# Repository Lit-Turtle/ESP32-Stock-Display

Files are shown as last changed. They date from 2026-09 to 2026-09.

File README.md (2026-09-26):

# ESP32-Stock-Display

https://github.com/user-attachments/assets/17d52d09-3d5c-4d5f-b84c-951d37e83fe0

This project displays live stock prices on a mirror-like display, with display specifics easily changeable through a local network(access point). The ESP32 acts as a STA mode enabling this to be a true IOT device. A robust power system allows this device to run on the recommended 9V from a USB-C input; switch on side to easily enable or disable the device; and a photoresistor to automatically turn off the device when the environment is dark. 

## Features

- 32 by 8 dot matrix display to easily display stock prices and animations.
- Mirror-like display that hides the grid pattern from dot matrix only allowing the powered lights to shine through.
- Wall anchors to easily setup display using screws or any wall hooks. 
- USB-C power plug, used for its widespread usage and that many people already have one.
- Robust power system, with side switch to quickly disable the display. Adjustable circuit that reactively cuts power if the surrounding environment is dark, for when sleeping or room lights or turned off. 
- Local network set up through the ESP32 allows any internet device connected to the same network to change what the display shows. 
- IOT device capabilities through the ESP32 connected to your wifi network, which grabs the live stock prices and the fear & greed index. 

## Tech Stack

**Hardware:** ESP32, MAX7219 32×8 LED Matrix, LM393 Comparator, NMOSFET, Photoresistor, USB-C PD Module  
**Software:** C++, Arduino IDE, HTML/CSS, JavaScript  
**CAD/PCB:** SolidWorks, KiCad  
**Manufacturing:** JLCPCB, 3D Printing  
**Connectivity:** Wi-Fi, REST APIs, Local Web Server

## Goal

The goal of this project is to develop a functional IoT device that can be easily integrated into users’ life. More specifically, creating an affordable stock ticker that can be easily customized to match individual financial strategies. 

## Why?

Being introduced to investing from a young age, I decided one day I want to see how much a stock ticker would be if I got one. So like most I searched it up on Amazon to see that prices ranged from $50 to $100 plus. When I got my hands on an ESP32 for the first time, I realized that a stock ticker would be something I can build. 

## System Architecture

Stock Ticker System Arch

## Design Process

### Initial Design

The general idea for the stock ticker has remained the same throughout, which is to use the ESP32 as the microcontroller in order to get data and the dot matrix for the display. I did consider a LCD screen, however I went with a dot matrix as I already had it on hand and it would be easier to see from afar.

The casing was not as set in stone, however I had some key features that I wanted to implement. Which is a compact case with straightforward wiring, easy to access ESP32, and secure dot matrix holder with screen holder in front. 

The PCB that disables and enables power depending on surrounding light level, was not initially part of the plan. However, the idea came in during the early design process while an improved light system was an improvement already being considered.

### Hardware Selection

ESP32 microcontroller for its wifi and web server capabilities. A perfect beginner microchip for IoT projects and ability to be programmed with C++ on Arduino IDE.  

MAX7219 dot matrix chosen for its financial aesthetic. Ability to display still and scrolling text without the need for fonts, with relatively simple ways to draw art.

JLCPCB for PCB fabrication as they have been reliable and affordable throughout the time I have used their service. For this project I also utilized their parts assembly service to have them solder the resistors, LM393, potentiometer, and mosfet. A PCB was used for the power system as it requires a decent amount of components, so PCB saves space and decreases opportunity for error.    

### PCB Development

The PCB board also had a couple iterations. Some were due to errors that either made the board faulty or gave unintended results. Other than errors some key changes were the use of a potentiometer with now facing upwards instead to the side for easier access when placed in a narrow case. Another change was the location of the 2 wires in and 2 wires out which were moved for easier assembly when in case, as power input is located on one side while the load is located on the opposite end. 

An annoying roadblock I ran into was regarding KiCad and its mosfets. Most mosfets use pinout gate, drain, source, however kiCad actually does not have a default footprint for that so you have to edit the pin number accordingly. Or else once you go into the PCB editor it will say you have it traced correctly but once you solder your mosfet it won’t work because the pins are different. For my situation the mosfet was drain, gate, source but my real life mosfet was gate, drain, source. So I had to flip the pin number for drain pin and gate pin in the schematic editor, when you click on component and edit footprint. 

### Enclosure Development

The case had 3 iterations, however each iteration had only minor iterations. The 1st to 2nd: adjusting wall mounting hole placement, lowered esp32 area to give space to wires from bottom of ESP32, addition of wire passing area from ESP32 to dot matrix, resizing of USB-C hole, and holding side walls for PD module. 2nd to final iteration is just the addition PCB holding ramps in the power section.

The PD module holding cap piece had quite a few iterations due to the fittings/holding method making it too snug or too loose. With such small dimensions and scenarios where proper fit was needed it of course can with some iterations. Other than small dimension changes the main change was a roof over the screw terminals which greatly benefitted the fit. 

### Screen Development

The screen is a glass piece. For my display I ordered a plexiglass due to it being cheaper. Though, any see-through material with the matching dimensions can be used. 

Mirror Screen

In order to hide the grid pattern from the dot matrix, I tested a couple different options. First, was frosted glass film, however, this blurred the light or had no effect due to the fact that the matrix was right next to the glass. A tint is also an optional film, however I found that it often blurs the light a bit too much, making text a bit difficult to read.

The recommended option is to use some sort of tint, the darkness varies to preference. However, for my project I decided to use a one way mirror tint as it completely hides the grid. Additionally, when turned off it looked like a regular mirror but when enabled gave a cool light in mirror effect. The exact ordered materials can be found below in the parts list. 
The screen was an area that proved to be sort of difficult. If the piece fits the dimensions 147mm x 41mm x 4mm it will be a great fit for the case. For my project I ordered plexiglass and a couple different filters. I will later mention what I tried but what worked was the tinted mirror filter. However, if your budget is greater, I would recommend getting glass instead of plexiglass. The plexiglass, at least that I ordered, has some uneven/bumpy surface which makes the tint difficult to apply, but even once applied some bumps are still noticeable. It does not make the text illegible however for a better look, a glass piece would be recommended. 

## Light ON/OFF PCB Board

The circuit was first designed on a breadboard to test the circuit design and concept.

LightOnOFFBreadboard

LightOnOffSchematic

This circuit’s main component is the LM393 Comparator which compares the voltage between 2 input voltages. The 2 input voltages for our case will be determined by the photoresistor and potentiometer voltage dissipated. This means if potentiometer resistance is greater than photoresistor’s resistance then power is supplied and not supplied if reverse. Note that the photoresistor has increased resistance when dark. 

The 10k ohm resistor R3 acts as a pull-down resistor creating a potential difference to actually flow through the photoresistor so that there is voltage to be compared for the LM393, there must be a resistor in order to have the potential difference across be the full 9V through a voltage divider. The 10k ohm resistor R4 acts as a pull-up resistor because the LM393 is open-collector output. This is necessary for whenever the output is HIGH as it helps open the transistor gate. While the 1k ohm resistor R2 is necessary as the NMOSFET gate can cause current spikes and this resistor protects the comparator from these spikes. 

LightOnOffPCBEditor

Some key pieces to note are as follows. The vertical potentiometer though taking more space was selected for easier adjusting of potentiometer value due to the narrow width of the power area. Also the LM393 comparator has 2 comparators built in but only one was used. For my case I used pins 1, 2, and 3. It is key not to forget to connect pin 4 for ground and pin 8 for power in order to power the comparator. Another additional piece is the logo engraved in the top right, which was added for a more professional look and for copyright protection.

SolderedPCB

The PCB board was designed using kiCad and manufactured by JLCPCB. Some components were also soldered by JLCPCB.

## Enclosure

The shell of our display has 3 main pieces and one additional piece. Each part was designed in SolidWorks. 

CaseBaseShaded

The first and most important piece is the base piece, which is the largest piece which holds all the components. The base piece has 3 main sections. The first is our power area which is where our switch, power input, and our pcb board will be located. The one connected to that is where our ESP32 will be located. The big area is then where our dot matrix display will be located and as you can see we have the small area to the right of that which is where the wiring between the ESP32 and dot matrix will pass through. 

CaseCHolder

Some key features of the base is a cut out and shaping of our USB-C plug, which was designed to securely hold the PD lonely binary module.

CaseIndent

CaseWallMountShaded

Another important area is the indent which will be important when it comes to our third piece. Lastly our wall mount which was designed for screws drilled into the wall or any similar mounting piece. This is an optional piece only for those who want to mount the display on a wall. However, this neat design allows for easy hooking of display if you choose to do so.  



The second piece is the roof of our case. This piece encloses the entire display. Attached to the base via the 4 aligning holes that were seen on the base. Which can then be connected using screws of your choice. There is one non-circular hole which is where you should pass the photoresistor through.

DisplayScreen

The last piece is a purchased piece and is the glass used to not only hold the matrix upright but also as a protector/screen for our display. This piece is also where chosen filters or tints can be applied onto. The main thing is the dimensions of the class, which is recommended to be 147mm x 41mm x 4mm. 

## Electrical/Wiring

The wiring of the display is relatively simple. Going by each section of the base it will be as follows.

For the power area, the power will first start from our PD USB-C module. This module was selected for its capabilities to easily switch between different voltage supplies. 

PD Module

This module will have 2 wires for power and ground. The positive end will then connect in series with the switch, which will connect to the PCB board along with our ground. Exiting the PCB board will be the load voltage out and load voltage back. These 2 wires will be the only 2 leaving from the power area.

These 2 wires will simply connect to the Vin and GND of the ESP32 located in the adjacent section.

Between the dot matrix and ESP32 will be 5 separate wires: VCC, GND, DIN, CS, and CLK. These should connect to the corresponding pins in the code, which will be discussed next.

## ESP32 Code

The ESP32 was programmed through the Arduino IDE. The entire details of the code will not be explained here as the code already contains comments.

Libaries from Arduino IDE used in this program are:
- ArduinoJson by Benoit Blanchon
- MD_MAX72XX by majicDesigns
- MD_Parola by majicDesigns

The ESP32 is established as STA and AP mode, which means you will need to enter your own wifi network information for the ESP32 to function properly. You will also need to import some libraries for you to set up local sites and display everything text/images on the matrix. 

The key idea is that through the site users can select different modes that change what the display shows. If we are displaying stock prices or fear & greed indexes, the ESP32 will grab these prices or index through an api key and display the data.

You may easily add or modify existing modes to display what you would like. To add mode you would need to modify the 
```
enum DisplayMode { MODE_VOO, MODE_FEAR_GREED… };
```
Just add or remove any modes you would like. Then add or remove that option from our switch case.
```
switch(currentMode) {
	case MODE_VOO:
		html += “VOO Price”;
		break;
	case MODE_FEAR_GREED:
		html += “FEAR GREED INDEX”;
		break;
	…
}
```
A few lines down add options as well.
```
html += “<option value=’voo’” + String(currentMode == MODE_VOO ? “ selected” : “”) + “>VOO Price</option>”;
```

You will also need to add your new mode on line 265. 
```
If (mode == “voo”) 
	currentMode = MODE_VOO;
```
Lastly, in refreshData() you will also want to add another case for your new mode. 
```
void refreshData() {
 	String text;
  	switch (currentMode) {
    		case MODE_VOO:        
      		text = "" + getVOO();  
      		break;
```

If you are going to be grabbing data you may want to create a new get_() method. 

I will not bore you with the entire explanation but the code, with comments, will be included in this repository. 

## Final Assembly

https://youtu.be/V5j7vDCx7zQ

For a step-by-step guide to assembling the enclosure and electronics, see the [Assembly Guide](ASSEMBLY.md).

## Future Improvements

Some future improvements I would like to make is having a multi-color matrix display, so that way the color can indicate whether price is up or down and fear or greed. 

Another area is with the code, through the STA and AP mode with the matrix display, the display can really display any data you would like, just by modifying the code. Some examples are sport scores, Spotify listening/lyrics, weather, and any information you can grab data for.

## Parts List

[Filament](https://store.creality.com/products/hyper-pla-rfid-3d-printing-filament-1kg)

[Plexiglass](https://www.aliexpress.us/item/3256803346944118.html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)
Specific dimensions may need to be requested.

[Regular Tint](https://www.aliexpress.us/item/3256806769429614.html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) 

[Mirror Tint](https://www.aliexpress.us/item/3256805054544955.html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)

[PD Module](https://www.amazon.com/dp/B0GTTTGJNX?ref=ppx_yo2ov_dt_b_fed_asin_title)

[ESP32 Dev Kit](https://www.amazon.com/AITRIP-ESP-WROOM-32-Development-Microcontroller-Integrated/dp/B0CR5Y2JVD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)

[Dot Matrix](https://www.aliexpress.us/item/3256805668841965.html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)

[Switch](https://www.aliexpress.us/item/3256809828963002.html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)

[Photoresistor](https://www.amazon.com/dp/B0CM5YNGSF?ref=ppx_yo2ov_dt_b_fed_asin_title&th=1)

[Heat Press Thread Insert](https://www.amazon.com/dp/B0CTCH68LT?ref=ppx_yo2ov_dt_b_fed_asin_title)

[M3 8mm Screws](https://www.amazon.com/dp/B07CMSBQ11?ref=ppx_yo2ov_dt_b_fed_asin_title&th=1)

---

Part Number for Components

Potentiometer: LCSC Part # C116302

LM393 Comparator: LCSC Part # C5252905

NMOSFET: LCSC Part # C2557

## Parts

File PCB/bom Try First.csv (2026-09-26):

Designator | Footprint | Quantity | Value | LCSC Part #
Q1 | TO-220F-3_Vertical | 1 | NMOS | C2557
R1 | R_LDR_D6.4mm_P3.4mm_Vertical | 1 | R_Photo
R2 | 805 | 1 | 1kR | C17513
R3, R4 | 805 | 2 | 10kR | C17414
RV1 | Potentiometer_Bourns_3386P_Vertical | 1 | R_Pot | C116302
U1 | DIP-8_W7.62mm | 1 | LM393P | C5209
U2 | 9V Input | 1 | ~
U3 | 9VLoadFoot | 1 | ~

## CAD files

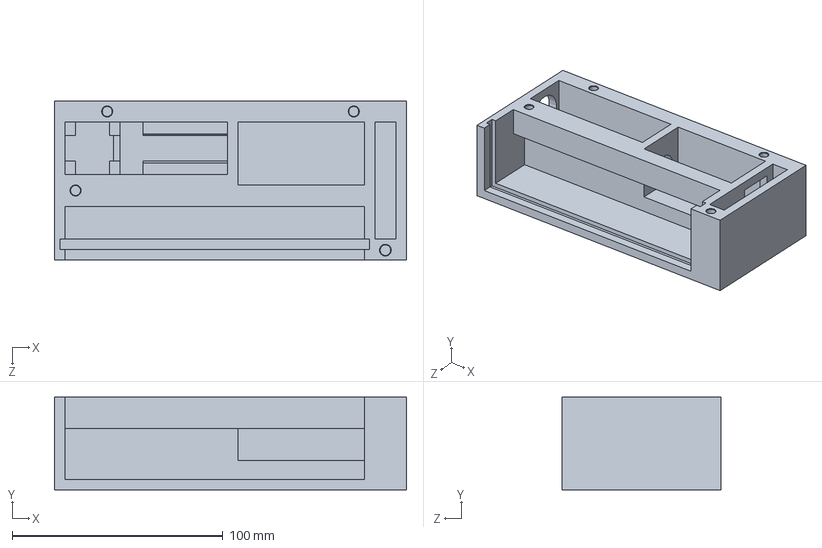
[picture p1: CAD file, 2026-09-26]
Part Files/Main Base/Stock Display Main Holder.SLDPRT
167.0 x 44.0 x 75.5 mm

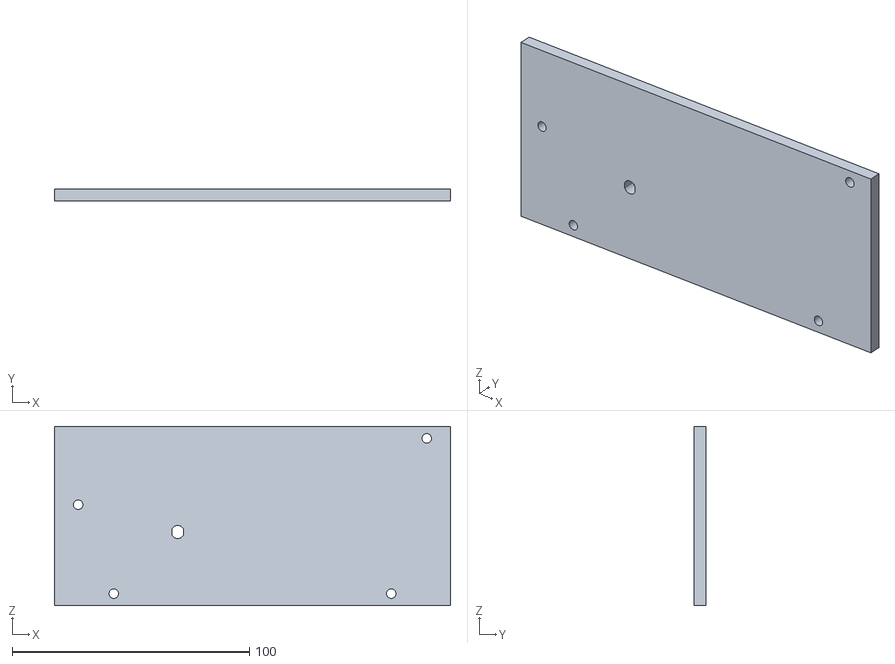
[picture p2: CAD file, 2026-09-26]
Part Files/Roof/Stock Display RoofF.STL
167.0 x 5.00 x 75.5

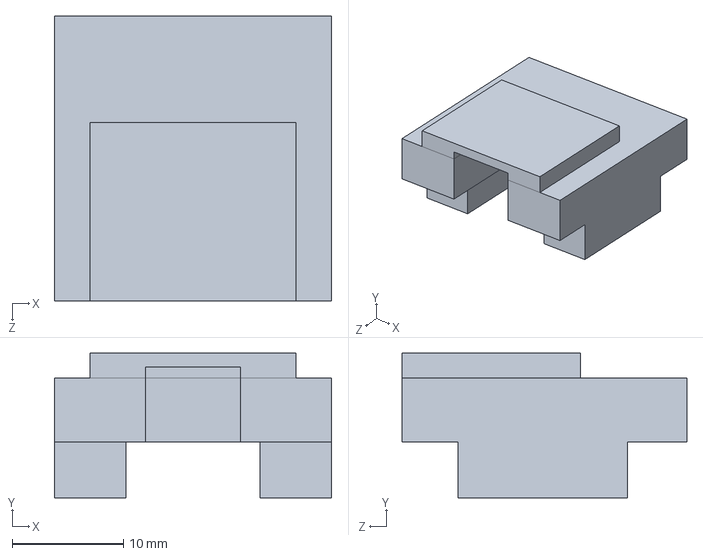
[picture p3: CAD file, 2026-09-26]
Part Files/TypeC Cover/TypeC Slot Cover.SLDPRT
24.9 x 13.0 x 25.6 mm

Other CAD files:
Part Files/Main Base/Stock Display Main HolderF.STL
Part Files/Roof/Stock Display Roof.SLDPRT
Part Files/TypeC Cover/TypeC Slot CoverF.STL

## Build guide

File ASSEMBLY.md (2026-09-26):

# Assembly Instructions

## 1. Prepare the Case

3D print all three pieces of the case:

- Base
- Roof
- Cap

Remove all supports from the three pieces.

3DPrintedPieces1

## 2. Order the PCB and Components

Order the PCB using the included BOM and CPL files. JLCPCB is recommended if using these files.
You will also need to order the following components:

- Switch
- PD module
- ESP32 development board
- Photoresistor
- Dot matrix display
- Screen filter or tint
- Screen

The screen can be glass, plexiglass, acrylic, or a similar material. The recommended dimensions are: 147 mm x 41 mm x 4 mm

Components2

## 3. Check the Fit

Before assembling anything, make sure all of the components fit properly in the case.

The PD module should slide between the blocks in the power section and fit underneath the PD module cap. Make sure the USB-C port lines up with the opening on the side of the case.
Check that the switch fits properly in its opening.

The dot matrix should fit between the screen and the case. Also make sure the screen can slide into its slot with the dot matrix positioned behind it.

Placement3

## 4. Prepare the PCB

Solder all of the required components onto the PCB.

If you are using JLCPCB with the included BOM and CPL files, most of the components will already be assembled. You will only need to solder the 10k ohm photoresistor and the wires for Vin, Vout, and GND.

Leave the Vout and GND wires longer than the Vin wire. The extra length will make the later assembly easier.

Your finished PCB should look similar to the reference image.

Board4

You may also need to solder the screw terminal onto the PD module if it does not already have one installed.

## 5. Install the PD Module and PCB

All of the electronics will be installed inside the base.

Start with the power section. Place the PD module into its designated location and adjust it so the USB-C port is as flush with the side of the case as possible.

CaseBaseShaded

Place the PCB on top of the two rails in the base. The Vin side of the PCB should face the switch and outside of the case, while the Vout side should face the ESP32 and center of the case.

## 6. Connect the Power Switch

Before connecting the wires to the switch, connect the wire from the PD module to the VCC screw terminal.

A red wire is recommended for this connection to make the wiring easier to identify, although the color is not required.

Insert the exposed copper strands into the VCC screw terminal and tighten the screw until the wire is secure.

Do not connect the other end of this wire to the switch yet. Leaving the wire disconnected makes it easier to install the switch later.

Next, solder the other switch wire to the Vin connection on the PCB. You can solder the wire directly into the Vin hole, but using a separate connection point may make the assembly easier to work with.

Connect the GND wire next to Vin to the GND screw terminal on the PD module.

At this point, the PD module should have its VCC connected to the switch wire and its GND connected to the PCB GND. The two switch wires should still be disconnected from the physical switch.

Place the PD module cap over the module and adjust both pieces until the USB-C port is properly aligned with the opening in the case.

## 7. Install the Switch

Slide the switch into its opening with the switch facing outward.

Make sure the tabs on the switch are vertical. The outer tab should be closer to the screen side of the case and farther away from the back wall.

Once the switch is positioned correctly, connect the red wire from the PD module VCC terminal to the outer tab.

Connect the black wire from PCB Vin to the middle tab.

PowerArea5

## 8. Connect the ESP32 Power

Route the Vout and GND wires from the PCB through the circular hole into the ESP32 section.

The ESP32 and dot matrix will share the same power connections, so the Vout and GND wires need to be split into parallel connections.

Strip a small section of insulation from the middle of the Vout wire. Take another wire, preferably the same color, and wrap the exposed end around this section. Solder the connection.

Repeat the same process for the GND wire.

Splits6

The resulting connections should provide power to both the ESP32 and the dot matrix.

Vout should connect to ESP32 Vin and dot matrix VCC.

GND should connect to ESP32 GND and dot matrix GND.

## 9. Connect the ESP32 to the Dot Matrix

There are two ways to connect the ESP32 to the dot matrix.

### Jumper Wires

This method is recommended if your dot matrix already has pin headers installed.

Install the required pin headers on the ESP32 and use jumper wires to connect the ESP32 to the corresponding pins on the dot matrix.

PinHeader7

Route the wires through the narrow section on the side of the case where the dot matrix is located. The connections should remain toward the ESP32 side.

WirePass8

### Direct Wiring

Alternatively, you can solder wires directly between the ESP32 and the dot matrix.

The wires can be routed through the side opening or through the gap between the ESP32 and dot matrix sections.

Make sure the DATA, CS, and CLK connections match the pins specified in the code.

## 10. Install the Screen

Make sure the screen can slide completely into its slot with the dot matrix positioned behind it.

Do not force the screen into place. If it does not fit properly, check the position of the dot matrix and the screen dimensions.

AllPieces8

## 11. Program the ESP32

Install the Arduino IDE on your computer and set up the ESP32 board through the Arduino IDE Board Manager.

Connect the ESP32 to your computer using a USB to USB-C data cable. If your ESP32 uses Micro-USB, use a Micro-USB data cable instead.

Download or copy the project code from the GitHub repository and open it in Arduino IDE. 

Make sure you have the following libaries downloaded from Arduino IDE:
- ArduinoJson by Benoit Blanchon
- MD_MAX72XX by majicDesigns
- MD_Parola by majicDesigns

Before uploading the code, enter your Wi-Fi information in the following variables:
1. network_name
2. wifi_password

Enter your Wi-Fi network name for `network_name` and your Wi-Fi password for `wifi_password`.

Code to Edit

This connection is required for the ESP32 to retrieve data from the internet.

Select the correct ESP32 board and COM port, then upload the code.

The upload may take a few moments. Once the ESP32 connects successfully, the Serial Monitor should provide a link to the device's web interface.

There is an optional fear and greed index method that uses cloudflare worker agent. The code for the agent is included here [Worker](src/worker.js). However, you will need to set it up.

Once you have the link, upload it to the commented out method and put the link `http.begin("agent link");`

The other method does work, but values may be delayed or off from general index.

## 12. Test the Display

The display should show a pair of eyes after the code has been uploaded.

EyeScreen9

Open the web interface on another device connected to the same Wi-Fi network. From this page, you can change the information displayed on the matrix.

NetworkWebsite

If the dot matrix turns on with every LED illuminated, the DATA, CS, or CLK connections are most likely incorrect. Check that these connections match the pins defined in the ESP32 code.

ESP32-Pinout

Do not continue with the final assembly until the display and web interface are working correctly.

## 13. Final Assembly

Once everything has been tested, press the components into their proper locations inside the base.

Make sure all components are below the top of the case so the roof can be installed. The photoresistor should remain exposed so it can pass through the opening in the roof.

If you are using heat-set threaded inserts, install them into the four holes on the top of the base.

Heat Threads

Place the roof onto the base and guide the photoresistor through its opening. The photoresistor opening is slightly different from the four screw holes.

PhotoThrough Roof

Install a screw into each of the four screw holes and tighten them until the roof is secure.

The assembly is now complete.

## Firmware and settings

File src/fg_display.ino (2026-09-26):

/**
* Kaipo Ojas
* fg_display.ino
*/

#include <WiFi.h>
#include <HTTPClient.h>
#include <ArduinoJson.h>
#include <WebServer.h>
#include <MD_Parola.h>
#include <MD_MAX72XX.h>
#include <SPI.h>
#include <ESPmDNS.h> 
#include "MD_EyePair.h"
/**
* This program uses the ESP32 DevKit module to display various stock prices.
* Stocks display on a dot matrix display. 
* ESP32 is in STA and AP mode. Acts as STA to get current stock prices using apiKeys.
* ESP32 AP mode creates a local site for devices connected to same network to set what the display shows.
*/
#define DATA_PIN 23
#define CLK_PIN  18
#define CS_PIN   5
#define HARDWARE_TYPE MD_MAX72XX::FC16_HW
#define MAX_DEVICES   4

/**
* Network name/SSID
*/
const char* STA_SSID = "network_name";

/**
* Network password.
*/
const char* STA_PASS  = "network_password";

/**
* Access Point Name
*/
const char* AP_SSID  = "StockDisplay";

/**
* Access Point Password
*/
const char* AP_PASS  = "12345678";

String apiKey = "YOUR_ALPHA_VANTAGE_KEY";

//Used to display text
MD_Parola display = MD_Parola(HARDWARE_TYPE, DATA_PIN, CLK_PIN, CS_PIN, MAX_DEVICES);

//Used to display custom symbols(for eyes)
MD_MAX72XX mx = MD_MAX72XX(HARDWARE_TYPE, DATA_PIN, CLK_PIN, CS_PIN, MAX_DEVICES);

//Sets up Web server
WebServer server(80);

//Display Modes avilable
enum DisplayMode { MODE_VOO, MODE_FEAR_GREED, MODE_TEST, MODE_EYE, MODE_REPORT };
DisplayMode currentMode = MODE_TEST; //Initially sets to Test/Nothing shows

unsigned long lastUpdate = 0;

MD_EyePair eyes;

int currentBrightness = 1;

// ____Forward declarations __________
void connectSTA();
void createAP();
void handleRoot();
void handleSet();
void refreshData();
String getVOO();
String getFearGreed();
void showMessage(String msg);
String webpage();

/**
* Sets up dot matrix display, creates our AP site, and sets up STA mode.
*/
// ___Setup _____________
void setup() {
  Serial.begin(115200);
  //Sets up matrix display. Both Parole and MDMAXX
  mx.begin();

  display.begin();
  display.setIntensity(1);
  display.displayClear();

  eyes.begin(1, &mx, 500);

  //Connects ESP to our wifi as STA mode.
  WiFi.mode(WIFI_AP_STA);
  connectSTA();
  //Sets up the AP local site.
  createAP();

  server.on("/",    handleRoot);
  server.on("/set", handleSet);
  server.begin();

  if (MDNS.begin("stockdisplay")) {
    Serial.println("mDNS started - access at http://stockdisplay.local");
  }
}

// ______Loop___________
/**
* Loop / Running of program. Calls methods
*/
void loop() {
  server.handleClient();

  if (currentMode == MODE_EYE) {
    eyes.animate();
  }

  if (currentMode == MODE_REPORT) {
    if (display.displayAnimate()) {
      display.displayReset();
    }
  }

  if (millis() - lastUpdate > 300000) {
    lastUpdate = millis();
    if(currentMode != MODE_EYE) {
      display.begin();
      display.setIntensity(1);
      display.displayClear();
      refreshData();
    }
  }
}

// _____WiFi _________
/**
* Connects the ESP to the network.
*/
void connectSTA() {
  WiFi.begin(STA_SSID, STA_PASS);
  Serial.print("Connecting to WiFi");
  int attempts = 0;
  while (WiFi.status() != WL_CONNECTED && attempts < 20) {
    delay(500);
    Serial.print(".");
    attempts++;
  }
  if (WiFi.status() == WL_CONNECTED) {
    Serial.println("\nConnected! IP: " + WiFi.localIP().toString());
  } else {
    Serial.println("\nFailed to connect to WiFi (continuing in AP-only mode)");
  }
}

/**
* Creates and setups the AP local site.
*/
void createAP() {
  WiFi.softAP(AP_SSID, AP_PASS);
  Serial.println("AP started. IP: " + WiFi.softAPIP().toString());
}

// _______Web server handlers____________
/**
* The webpage to be displayed by the AP.
*/
String webpage() {
  String html;
  html += "<!DOCTYPE html><html><head>";
  html += "<title>Stock Display</title>";
  html += "<meta name='viewport' content='width=device-width,initial-scale=1'>";
  html += "<style>";
  html += "body{margin:0;min-height:100vh;display:flex;flex-direction:column;justify-content:center;align-items:center;font-family:georgia;background:#0a0a14;color:#4444ff;}";
  html += "h1{text-align:center;font-size:5vw;color:#3d7eff;text-shadow:0 0 10px #2233ff;}";
  html += ".card{background:#0a0a14;padding:30px;min-width:300px;text-align:center;}";
  html += ".current{font-size:1.2vw;margin-bottom:20px;color:#888;}";
  html += ".current span{color:#3d7eff;font-weight:bold;}";
  html += "select{font-size:1.5vw;border:2px solid #3d7eff;border-radius:3px;background:#0a0a14;color:#3d7eff;padding:5px;width:100%;margin-bottom:20px;}";
  html += "select option{background:#0a0a14;color:#3d7eff;}";
  html += ".brightness-label{font-size:1.2vw;margin-bottom:8px;display:block;}";
  html += "input[type=range]{width:100%;accent-color:#3d7eff;margin-bottom:20px;}";
  html += "input[type=submit]{background:#3d7eff;color:#0a0a14;border:none;padding:10px 30px;font-size:1.2vw;font-family:georgia;border-radius:3px;cursor:pointer;width:100%;font-weight:bold;}";
  html += "input[type=submit]:hover{background:#2233ff;box-shadow:0 0 10px #3d7eff;}";
  html += ".brightness-val{font-size:1vw;color:#888;}";
  html += "</style></head><body>";
  html += "<div class='card'>";
  html += "<h1>Stock Display</h1>";

  html += "<div class='current'>Currently showing: <span>";
  switch(currentMode) {
    case MODE_VOO:        
      html += "VOO Price"; 
      break;
    case MODE_FEAR_GREED: 
      html += "Fear &amp; Greed"; 
      break;
    case MODE_EYE:        
      html += "Eyes"; 
      break;
    case MODE_REPORT:     
      html += "Report"; 
      break;
    default:              
      html += "Test"; 
      break;
  }
  html += "</span></div>";

  html += "<form action='/set' method='get'>";
  html += "<select name='mode'>";
  html += "<option value='voo'" + String(currentMode == MODE_VOO ? " selected" : "") 
          + ">VOO Price</option>";
  html += "<option value='fear'" + String(currentMode == MODE_FEAR_GREED ? " selected" : "") 
          + ">Fear &amp; Greed</option>";
  html += "<option value='eyes'" + String(currentMode == MODE_EYE ? " selected" : "") 
          + ">Eyes</option>";
  html += "<option value='report'" + String(currentMode == MODE_REPORT ? " selected" : "") 
          + ">Report</option>";
  html += "<option value='test'" + String(currentMode == MODE_TEST ? " selected" : "") 
          + ">Test</option>";
  html += "</select>";

  html += "<label class='brightness-label'>Brightness: <span class='brightness-val' id='bval'>" + String(currentBrightness) + "</span></label>";
  html += "<input type='range' name='brightness' min='0' max='15' value='" + String(currentBrightness) + "' oninput=\"document.getElementById('bval').innerText=this.value\">";

  html += "<input type='submit' value='Set'>";
  html += "</form>";
  html += "</div>";
  html += "</body></html>";
  return html;
}

/**
* Sends GET method when webpage is opened.
*/
void handleRoot() {
  server.send(200, "text/html", webpage());
}

/**
* Updates mode when updated through webpage.
*/
void handleSet() {
  if (server.hasArg("brightness")) {
    currentBrightness = server.arg("brightness").toInt();
    display.setIntensity(currentBrightness);
  }

  if (server.hasArg("mode")) {
    String mode = server.arg("mode");

    if (mode == "eyes") {
      display.displayClear();
      mx.begin();
      mx.clear();
      eyes.begin(1, &mx, 500);
      currentMode = MODE_EYE;
    } else {
      display.begin();
      display.setIntensity(currentBrightness);  // use saved brightness
      display.displayClear();

      if (mode == "voo")    
        currentMode = MODE_VOO;
      else if (mode == "fear")   
        currentMode = MODE_FEAR_GREED;
      else if (mode == "report") 
        currentMode = MODE_REPORT;
      else                       
        currentMode = MODE_TEST;

      refreshData();
    }
  }
  server.send(200, "text/html", webpage());  // send back updated page instead of redirect
}
// ________Data fetching ____________
/**
* Gets the Vanguard S&P 500 ETF price
*/
String getVOO() {
  if (WiFi.status() != WL_CONNECTED) return "NO WIFI";

  HTTPClient http;
  http.begin("https://query1.finance.yahoo.com/v8/finance/chart/VOO?interval=1d&range=1d");
  http.addHeader("User-Agent", "Mozilla/5.0");
  int code = http.GET();

  if (code <= 0) {
    http.end();
    return "ERR";
  }

  DynamicJsonDocument doc(8192);
  deserializeJson(doc, http.getString());
  http.end();

  float price = doc["chart"]["result"][0]["meta"]["regularMarketPrice"].as<float>();
  float open  = doc["chart"]["result"][0]["meta"]["chartPreviousClose"].as<float>();

  if (price == 0) return "N/A";

  String direction = "";
  if (open != 0) {
    if (price > open)      
      direction = "U";
    else if (price < open) 
      direction = "D";
    else                   
      direction = "=";
  }

  return "$" + String((int)price) + direction;
}

/**
* Displays the current market fear and greed index.
*/  
String getFearGreed() {
  if (WiFi.status() != WL_CONNECTED) return "NO WIFI";

  HTTPClient http;
  http.begin("https://production.dataviz.cnn.io/index/fearandgreed/graphdata");
  int code = http.GET();

  if (code <= 0) {
    http.end();
    return "ERR";
  }

  DynamicJsonDocument doc(1024);
  deserializeJson(doc, http.getString());
  http.end();

  int value = doc["fear_and_greed"]["score"].as<int>();
  if (value == 0) return "N/A";
  
  String type = "";

  String classification = String(doc["fear_and_greed"]["rating"]);
  if (classification == "Extreme Greed") 
    type = "EG";
  else if (classification == "Greed")
    type = "G";
  else if (classification == "Extreme Fear")
    type = "EF";
  else if (classification == "Fear")
    type = "F";
  else
    type = "";

  return type + " " + String(value);  // just "65" to keep it short on display
}

/**
* Optional, but better fear and greed method that uses cloudflare agent.
*/
/*
String getFearGreed() {
  if (WiFi.status() != WL_CONNECTED)
    return "NO WIFI";

  HTTPClient http;
  //Just enter cloudflare worker link here for it to work.
  http.begin("agent link");

  int code = http.GET();

  if (code != HTTP_CODE_OK) {
    Serial.print("HTTP ERROR: ");
    Serial.println(code);

    http.end();
    return "ERR";
  }

  String payload = http.getString();
  http.end();

  Serial.println("FEAR/GREED:");
  Serial.println(payload);

  DynamicJsonDocument doc(512);

  DeserializationError error = deserializeJson(doc, payload);

  if (error) {
    Serial.print("JSON ERROR: ");
    Serial.println(error.c_str());
    return "JSON ERR";
  }

  int value = doc["score"] | -1;
  String classification = doc["rating"] | "";

  if (value < 0)
    return "N/A";

  String type;

  if (classification == "extreme greed")
    type = "EG";
  else if (classification == "greed")
    type = "G";
  else if (classification == "extreme fear")
    type = "EF";
  else if (classification == "fear")
    type = "F";
  else if (classification == "feutral")
    type = "N";

  return type + " " + String(value);
}
*/

/**
* Displays stock price of given symbol.
*/
String getStockPrice(String symbol) {
  if (WiFi.status() != WL_CONNECTED) return "ERR";

  HTTPClient http;
  String url = "https://query1.finance.yahoo.com/v8/finance/chart/" + symbol + "?interval=1d&range=1d";
  http.begin(url);
  http.addHeader("User-Agent", "Mozilla/5.0");
  int code = http.GET();

  if (code <= 0) { http.end(); return "ERR"; }

  DynamicJsonDocument doc(8192);
  deserializeJson(doc, http.getString());
  http.end();

  float price = doc["chart"]["result"][0]["meta"]["regularMarketPrice"].as<float>();
  float open  = doc["chart"]["result"][0]["meta"]["chartPreviousClose"].as<float>();

  if (price == 0) return "ERR";

  String direction = "";
  if (open != 0) {
    if (price > open) 
      direction = "U";
    else if (price < open) 
      direction = "D";
    else 
      direction = "=";
  }

  return symbol + " $" + String((int)price) + " " + direction;
}

/**
* Report mode. Shows various primary stock day performances.
*/
String buildTickerString() {
  String symbols[] = {
    "AMZN", "AAPL", "TSLA", "GOOGL",
    "BTC-USD", "ETH-USD", "JPM", "NVDA",
    "BRK-B", "MSFT", "META", "LLY"
  };
  String names[] = {
    "AMZN", "AAPL", "TSLA", "GOOG",
    "BTC", "ETH", "JPM", "NVDA",
    "BRKB", "MSFT", "META", "LLY"
  };

  int count = 12;
  String ticker = "";

  for (int i = 0; i < count; i++) {
    Serial.println("Fetching: " + symbols[i]);

    HTTPClient http;
    String url = "https://query1.finance.yahoo.com/v8/finance/chart/" + symbols[i] + "?interval=1d&range=1d";
    http.begin(url);
    http.addHeader("User-Agent", "Mozilla/5.0");
    int code = http.GET();

    if (code > 0) {
      DynamicJsonDocument doc(4096);
      deserializeJson(doc, http.getString());

      float price = doc["chart"]["result"][0]["meta"]["regularMarketPrice"].as<float>();
      float open  = doc["chart"]["result"][0]["meta"]["chartPreviousClose"].as<float>();

      String direction = "=";
      if      (price > open) direction = "U";
      else if (price < open) direction = "D";

      // Format to 2 decimal places
      char priceStr[12];
      dtostrf(price, 1, 2, priceStr);

      ticker += names[i] + " " + String(priceStr) + " " + direction + "  ";
    } else {
      ticker += names[i] + " ERR  ";
    }

    http.end();
    delay(100);
  }

  return ticker;
}

// _______Display_______
/**
* Shows the stock price on screen.
*/
void showMessage(String msg) {
  display.displayClear();
  display.setTextAlignment(PA_CENTER);
  display.print(msg.c_str());
}

/**
* Updates the mode when changed.
*/
void refreshData() {
  String text;
  switch (currentMode) {
    case MODE_VOO:        
      text = "" + getVOO();   
      break;
    case MODE_FEAR_GREED: 
      text = "" + getFearGreed();       
      break;
    case MODE_EYE:
      break;
    case MODE_REPORT:
      text = buildTickerString();
      display.displayClear();
      display.setTextAlignment(PA_LEFT);
      display.displayScroll(text.c_str(), PA_LEFT, PA_SCROLL_LEFT, 80);
      return;
    default:              
      text = "HELLO";             
      break;
  }
  showMessage(text);
}

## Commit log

2026-07-28 Update README with project details and features
    Added project description and features for ESP32-Stock-Display.
2026-07-28 Update image link for Light On/OFF PCB Board
2026-07-29 Enhance README with circuit and assembly details
    Expanded the README to include detailed explanations of the circuit design, components, wiring, and assembly instructions for the display case. Added images and a comprehensive parts list.
2026-07-29 Add fg_display.ino for stock price visualization
    Initial commit of fg_display.ino for stock price display using ESP32.
2026-08-10 Update README with roof piece details and sensor info
    Clarified the description of the roof piece and added details about the photo resistor sensor.
2026-09-26 Enhance README with project details and improvements
    Expanded the README to include detailed project features, tech stack, goals, design process, electrical wiring, final assembly, future improvements, and parts list.
2026-09-26 Create assembly instructions
2026-09-26 Update README with Assembly Guide reference
    Added a reference to the Assembly Guide for enclosure and electronics assembly.
2026-09-26 Document libraries used in ESP32 code
    Added libraries used in the ESP32 program to the README.
2026-09-26 Fix Cloudflare worker agent link in ASSEMBLY.md
    Updated the path for the Cloudflare worker agent code reference.
